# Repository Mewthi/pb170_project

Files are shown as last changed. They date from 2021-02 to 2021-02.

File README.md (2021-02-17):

LED - LA,LB,LC,LD,LE
Vstupy generovane citacom - (0-3)

    I       Q0    Q1    Q2    Q3    Q4
    00 -> ( 16 ->  8 ->  4 ->  2 ->  1)  
    01 -> ( 16 ->  1 ->  8 ->  2 ->  4) 
    10 -> ( 17 -> 10 ->  4 -> 20 -> 21)  
    11 -> (  4 -> 10 -> 17 -> 10 ->  4)  
  
Podrobna dokumentacia v /tex/main.pdf

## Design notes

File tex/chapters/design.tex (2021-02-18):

\newpage
\section*{Obvod}

Vstupy nášho obvodu sú generované čítačom:\\
a,Takto približne vyzeral čítač v simulátore Digital\\
\begin{center}
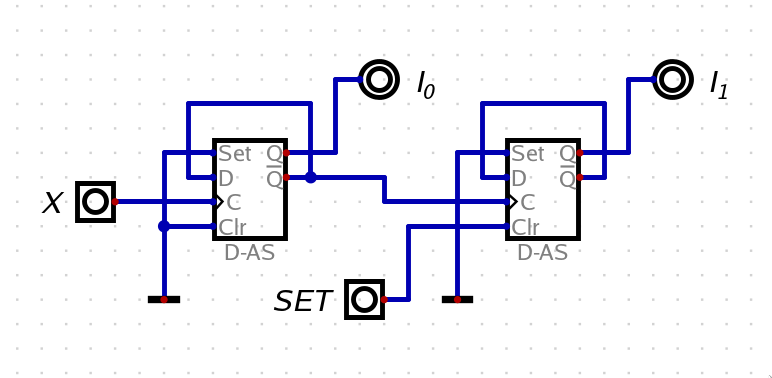
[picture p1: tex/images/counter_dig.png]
    
\end{center}
b,Pri návrhu PCB boli potrebné aj negácie a preto sme ich začali využívať.
\begin{center}
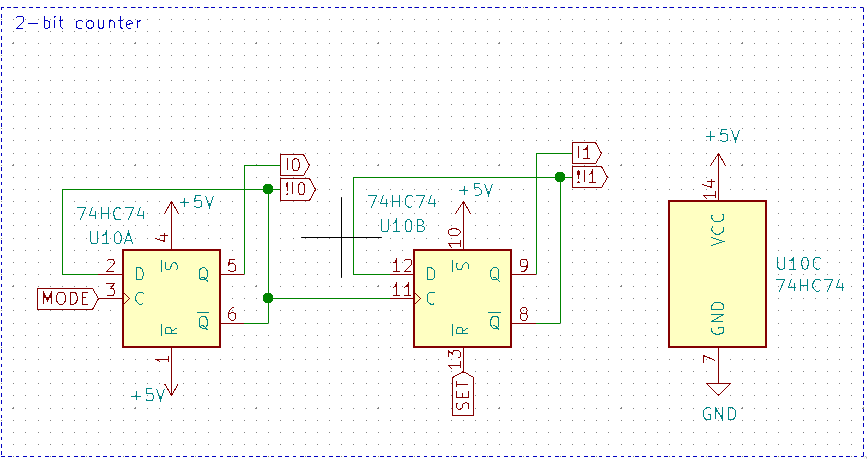
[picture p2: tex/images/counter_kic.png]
    	
\end{center}

\newpage
\noindent
Synchronizačný signál bol generovaný časovačom 555\\
\begin{center}
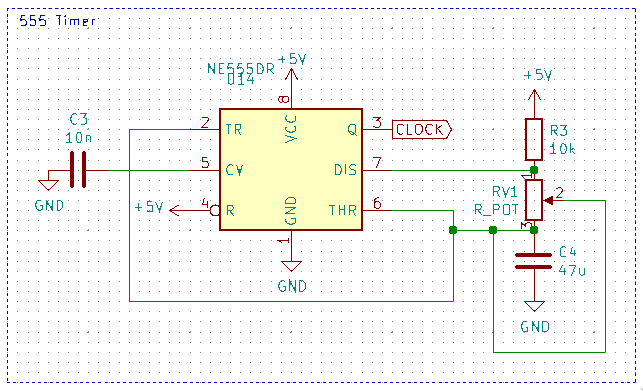
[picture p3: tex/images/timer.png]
    
\end{center}

\newpage
\noindent
Dve tlačítka ovládajúce tento obvod:\\
\noindent
a, tlačítko slúžiace na nastavenie prvého stavu sekvenčného obvodu:
\begin{center}
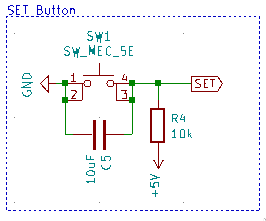
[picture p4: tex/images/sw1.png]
    
\end{center}
\noindent
b, tlačítko slúžiace na manipulovanie vstupov sekvenčného obvodu:
\begin{center}
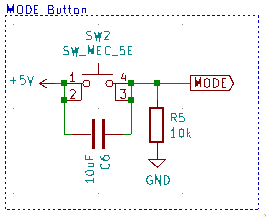
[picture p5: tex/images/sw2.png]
    
\end{center}

\newpage
\noindent
Samotný sekvenčný obvod v simulátore Digital a veľmi zjednodušená schéma celého obvodu:\\
\begin{center}
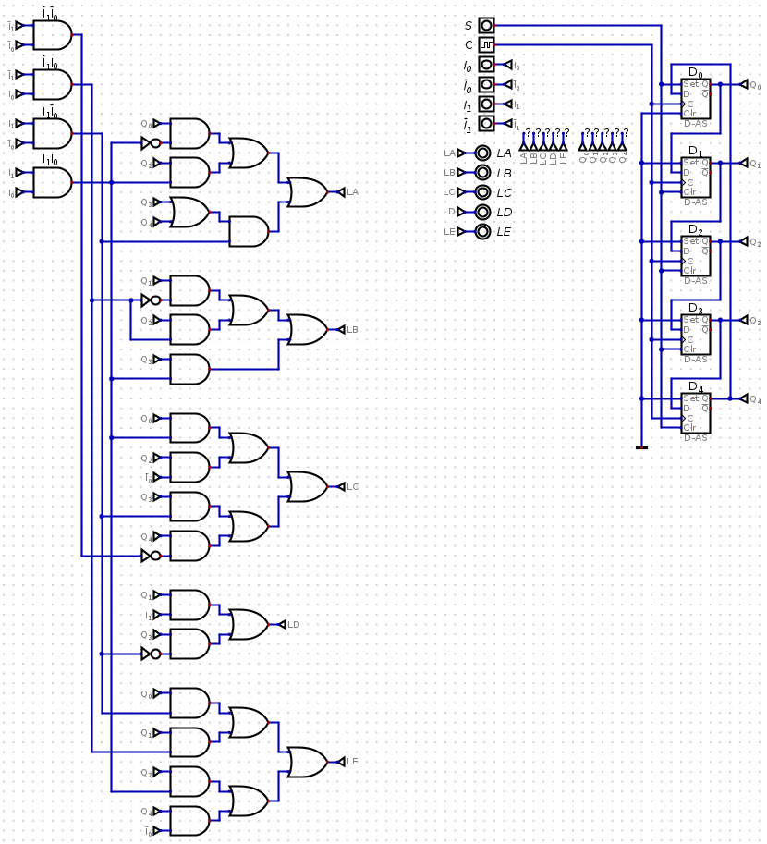
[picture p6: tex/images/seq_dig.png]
    
\end{center}

\begin{center}
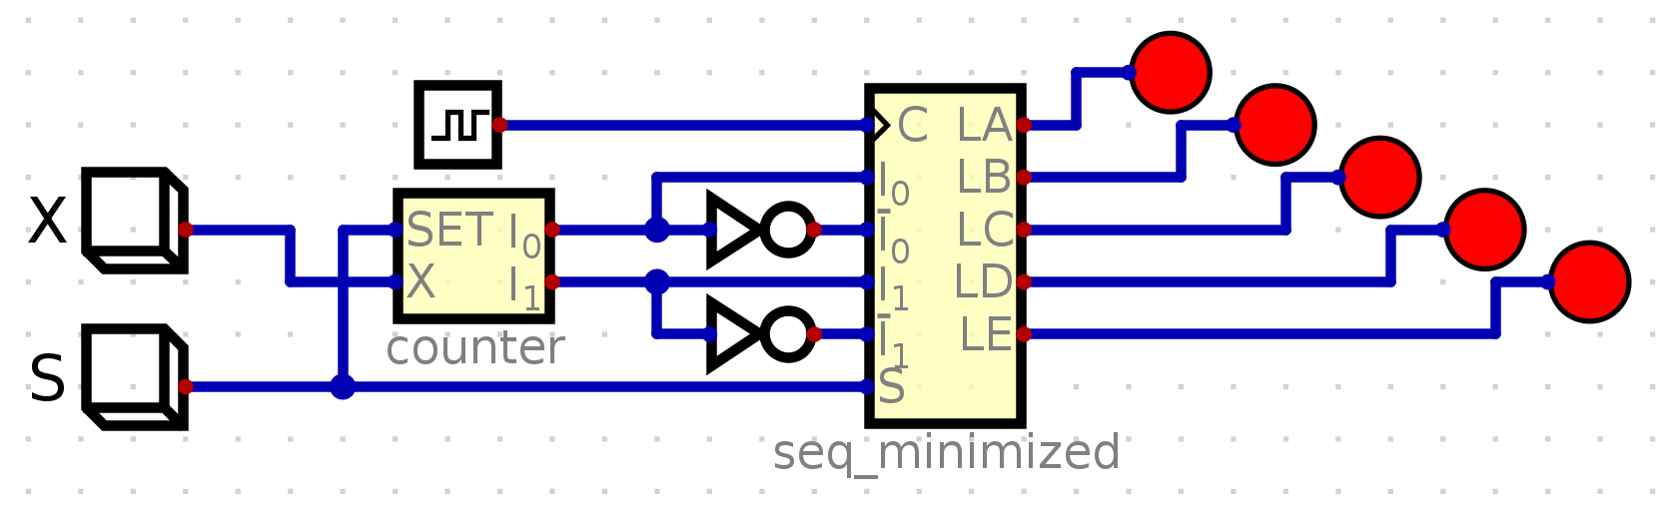
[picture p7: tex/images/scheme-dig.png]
    
\end{center}

\newpage
\noindent
Schéma celého obvodu
\begin{center}
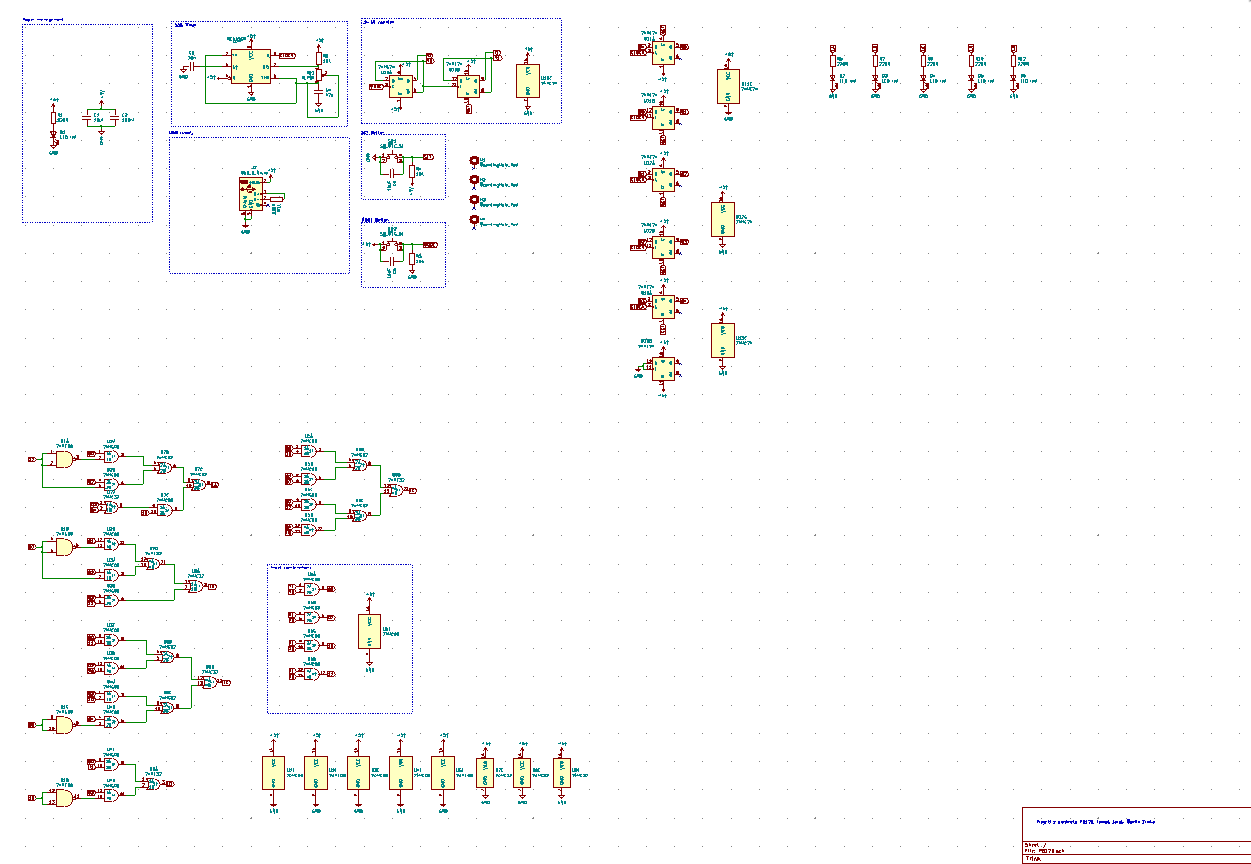
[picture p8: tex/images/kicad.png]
    
\end{center}
Schéma napájania, časovača, čítača a tlačítok.
\begin{center}
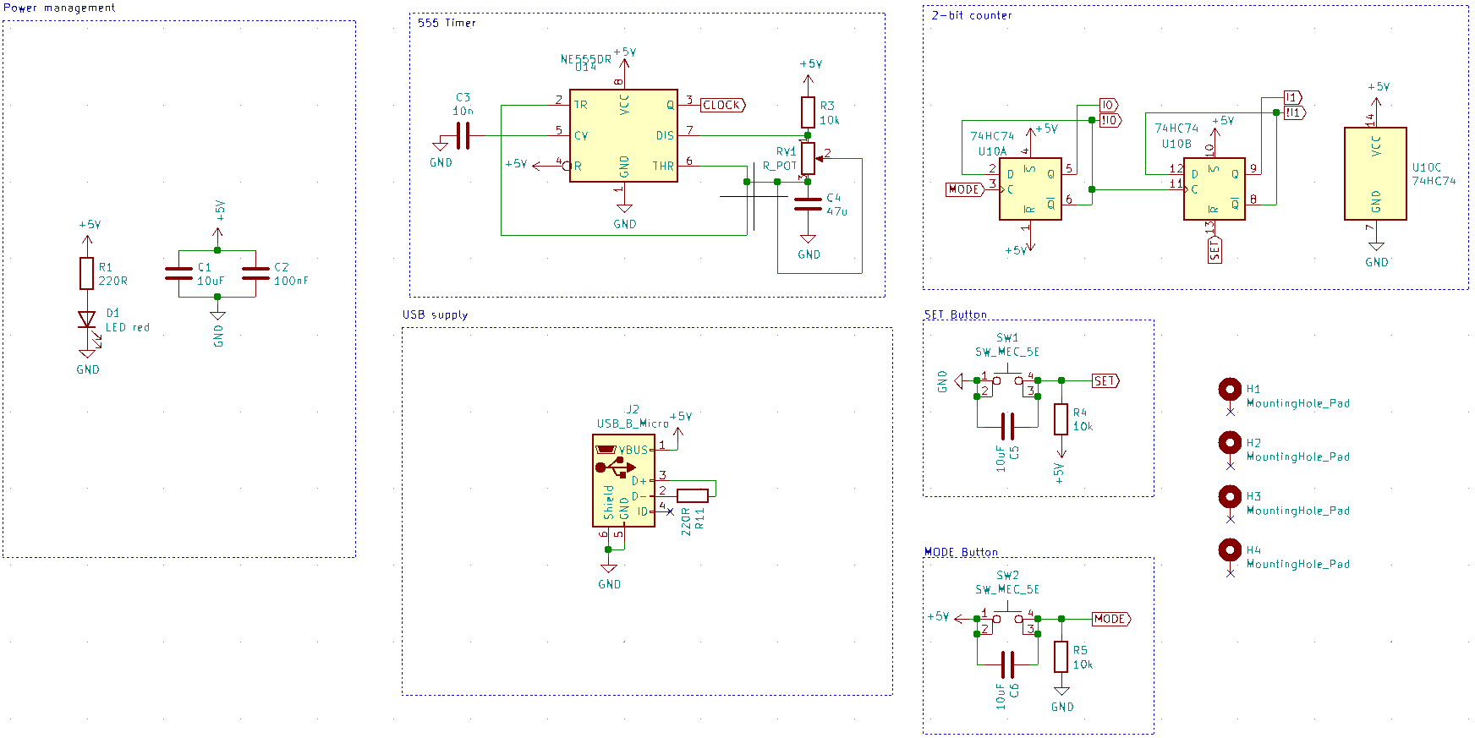
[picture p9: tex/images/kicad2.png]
    
\end{center}
\newpage
\noindent
Časť s klopnými obvodmi a LEDkami.
\begin{center}
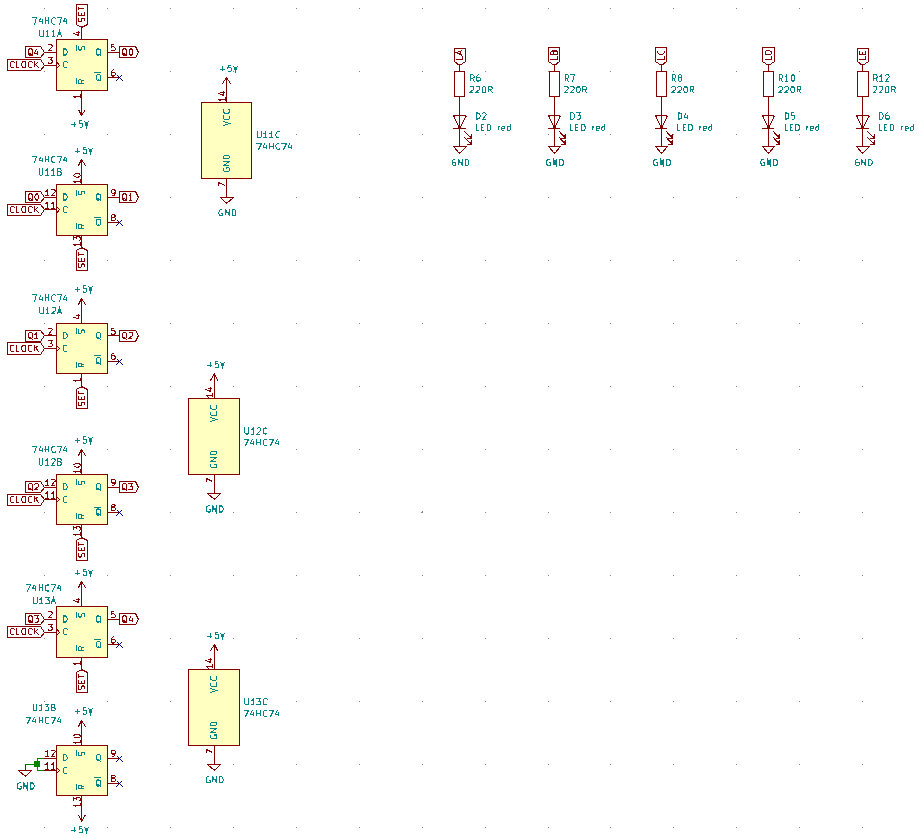
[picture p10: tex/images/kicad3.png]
    
\end{center} 
\newpage
\noindent
Logická časť obvodu.
\begin{center}
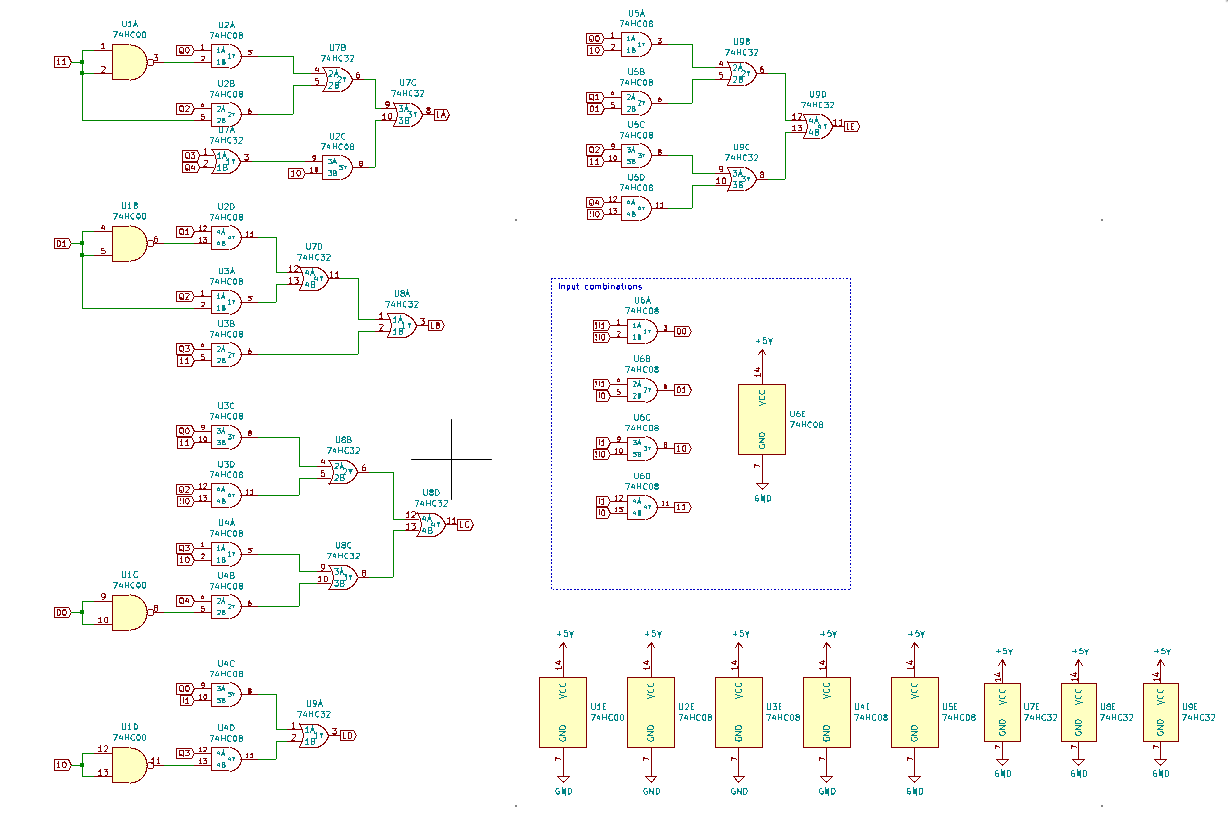
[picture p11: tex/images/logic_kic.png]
    
\end{center}
Prikladáme model výslednej PCB dosky.
\begin{center}
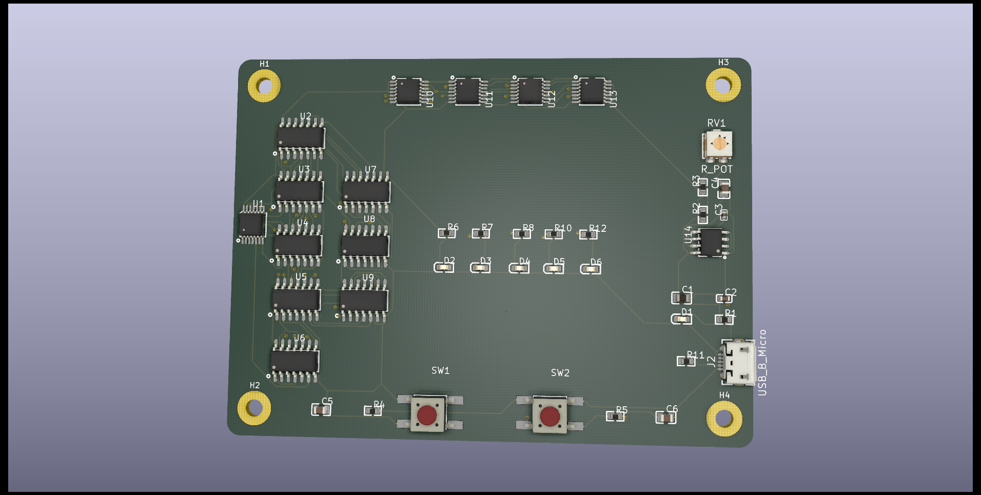
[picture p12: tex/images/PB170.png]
    
\end{center}

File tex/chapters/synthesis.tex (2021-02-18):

\graphicspath{{images/}}
\newcommand{\nt}[1]{\mkern 1.5mu\overline{\mkern-1.5mu#1\mkern-1.5mu}\mkern 1.5mu}

\section*{Syntéza sekvenčného obvodu}
\subsection*{Zadanie}
Našou úlohou bolo navrhnúť obvod, ktorý strieda farby blikaním niekoľkých farebných LED.
Tlačítkom change môže užívateľ vyberať medzi niekoľkými rôznymi sekvenciami blikania.
\subsection*{Priebeh návrhu}
Najprv sa bolo potrebné rozhodnúť z koľkých LEDiek bude náš obvod tvorený, ďalej
bolo potrebné rozhodnúť o počte druhov blikania týchto lediek.
Rozhodli sme sa, že náš obvod bude schopný riadiť blikanie 5 LEDiek štyrmi druhmi 
blikania.\\
Druhy blikania boli zvolené následovne: (Tieto desiatkové číslice predstavujú päťbitové binárne
čísla - jednotlivé LEDky)\\
\begin{center}
\begin{tabular}{c c c c c c c c c}
    16 &\rightarrow  &8 &\rightarrow  &4 &\rightarrow & 2 &\rightarrow  &1 \\
    16 &\rightarrow  &1 &\rightarrow  &8 &\rightarrow & 2 &\rightarrow  &4 \\
    17 &\rightarrow &10 &\rightarrow  &4 &\rightarrow &20 &\rightarrow &21 \\
    4 &\rightarrow  &10 &\rightarrow &17 &\rightarrow &10 &\rightarrow  &4 \\
\end{tabular}
\end{center}

\noindent
Ďalej sme vytvorili graf prechodov pre automat typu MEALY pre jednotlivé stavy tohto sekvenčného obvodu.
Vyzeral približne takto:
\begin{center}
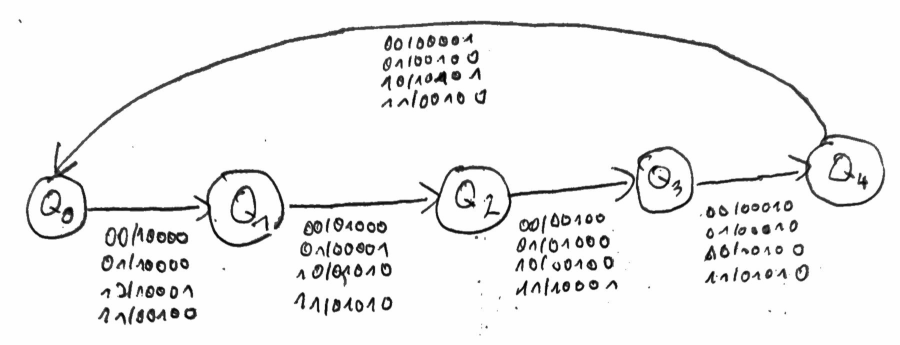
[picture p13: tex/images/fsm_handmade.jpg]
    
\end{center}

\newpage
\noindent
Na kódovanie vnútorných stavov $Q_{0}..Q_{4}$ sme použili kód 1zN a na ich uchovávanie
klopné obvody D. Vďaka použitému kódovaniu môžme budiace funkcie tohto sekvenčného 
obvodu odvodiť priamo z grafu prechodov.
\begin{align*}
    D_{0}^{n+1} &= Q_{4}\\
    D_{1}^{n+1} &= Q_{0}\\
    D_{2}^{n+1} &= Q_{1}\\
    D_{3}^{n+1} &= Q_{2}\\
    D_{4}^{n+1} &= Q_{3}\\
    LA &= Q_0(\nt{I_1}\nt{I_0} + \nt{I_1}I_0 + I_1\nt{I_0}) + Q_2(I_1I_0) +
    Q_3(I_1\nt{I_0}) + Q_4(I_1\nt{I_0})\\
       &=Q_0\nt{I_1I_0} + Q_2I_1I_0 + + (Q_3 + Q_4)I_1\nt{I_0}\\
    LB &= Q_1(\nt{I_1}\nt{I_0} + I_1\nt{I_0} + I_1I_0) + Q_2(\nt{I_1}I_0) + Q_3(I_1I_0)\\
       &= Q_1\nt{\nt{I_1}I_0} + Q_2\nt{I_1}I_0 + Q_3I_1I_0\\
    LC &= Q_0(I_1I_0) + Q_2(\nt{I_1}\nt{I_0} + I_1\nt{I_0}) + Q_3(I_1\nt{I_0}) +
    Q_4(\nt{I_1}I_0 + I_1\nt{I_0} + I_1I_0)\\
       &= Q_0I_1I_0 + Q_2\nt{I_0} + Q_3I_1\nt{I_0} + Q_4\nt{\nt{I_1}\nt{I_0}}\\
    LD &= Q_1(I_1\nt{I_0} + I_1I_0) + Q_3(\nt{I_1}\nt{I_0} + \nt{I_1}I_0 + I_1I_0)\\
       &= Q_1I_1 + Q_3\nt{I_1\nt{I_0}}\\
    LE &= Q_0(I_1\nt{I_0}) + Q_1(\nt{I_1}I_0) + Q_2(I_1I_0) + Q_4(\nt{I_1}\nt{I_0} +
    I_1\nt{I_0})\\
       &= Q_0I_1\nt{I_0} + Q_1\nt{I_1}I_0 + Q_2I_1I_0 + Q_4\nt{I_0}
\end{align*}

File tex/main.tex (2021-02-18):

\documentclass[12pt]{report}

\usepackage[utf8]{inputenc}
\usepackage{graphicx}
\graphicspath{{images/}}
\usepackage{amsmath}
\usepackage{geometry}
\geometry{
    left=1.5cm,
    right=1.5cm,
    top=1.5cm,
    bottom=1.5cm
}

\title{
{Záverečný projekt z predmetu PB170}\\
{\large Masarykova univerzita}\\
{\large Fakulta informatiky}
}
\author{Tomáš Jaroš a Martin Zimka}

\begin{document}

\maketitle

\input{chapters/synthesis.tex}
\input{chapters/design.tex}

\end{document}

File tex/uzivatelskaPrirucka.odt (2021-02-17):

UŽÍVATEĽSKÁ PRÍRUČKA

Sekvenčný obvod striedajúci farby blikaním 5 farebných LEDiek

Autori: Tomáš Jaroš a Martin Zimka


Všeobecný popis:

Blikanie LEDiek po napojení obvodu na napájanie spustíte stlačením SW1. Obvod začne blikať prvou sekvenciou. Postupním stláčaním tlačidla SW2 meníte sekvencie (druhá, tretia,…) až po štvrtej prídete zase na prvú (a takto stále dookola).

Ak chcete nejakú prebiehajúcu sekvenciu spustiť odzačiatku, stlačte tlačidlo SW1.

Rýchlosť blikania LEDiek si môžete upraviť potenciometrom.

Podporované sekvencie:

(LEDky sú označené zľava doprava písmenami A až E)

prvá ~> A → B → C → D → E

druhá ~> A → E → B → D → C

tretia ~> AE → BD → C → AC → ACE

štvrtá ~> AE → BD → C → BD

BAVTE SA :)

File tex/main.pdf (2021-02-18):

# Záverečný projekt z predmetu PB170

### Masarykova univerzita

### Fakulta informatiky

### Tomáš Jaroš a Martin Zimka

### February 18, 2021

## Syntéza sekvenčného obvodu

### Zadanie

Našou úlohou bolo navrhnúť obvod, ktorý strieda farby blikaním niekoľkých farebných LED. Tlačítkom change môže užívateľ vyberať medzi niekoľkými rôznymi sekvenciami blikania.

### Priebeh návrhu

Najprv sa bolo potrebné rozhodnúť z koľkých LEDiek bude náš obvod tvorený, dalej bolo potrebné ˇ rozhodnúť o počte druhov blikania týchto lediek. Rozhodli sme sa, že náš obvod bude schopný riadiť blikanie 5 LEDiek štyrmi druhmi blikania.
Druhy blikania boli zvolené následovne: (Tieto desiatkové číslice predstavujú päťbitové binárne čísla -jednotlivé LEDky)
16 → | 8 | → | 4 | → | 2 | → | 1
16 → | 1 | → | 8 | → | 2 | → | 4
17 → 10 → | 4 | → 20 → 21
4 | → 10 → 17 → 10 → | 4

Dalej sme vytvorili graf prechodov pre automat typu MEALY pre jednotlivé stavy tohto sekvenčného ˇ obvodu. Vyzeral približne takto:

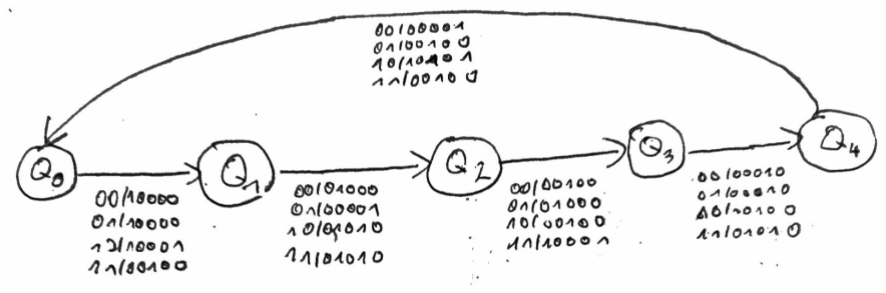
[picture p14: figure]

Na kódovanie vnútorných stavov Q0..Q4 sme použili kód 1zN a na ich uchovávanie klopné obvody D.
Vdaka použitému kódovaniu môžme budiace funkcie tohto sekvenčného obvodu odvodi ˇ | ť priamo z grafu
prechodov.

D

n+1
0 = Q4
D

n+1
1 = Q0
D

n+1
2 = Q1
D

n+1
3 = Q2
D

n+1
4 = Q3
LA = Q0(I1I0 + I1I0 + I1I0) + Q2(I1I0) + Q3(I1I0) + Q4(I1I0)
| = Q0I1I0 + Q2I1I0 + +(Q3 + Q4)I1I0

LB = Q1(I1I0 + I1I0 + I1I0) + Q2(I1I0) + Q3(I1I0)

| = Q1I1I0 + Q2I1I0 + Q3I1I0
LC = Q0(I1I0) + Q2(I1I0 + I1I0) + Q3(I1I0) + Q4(I1I0 + I1I0 + I1I0)
| = Q0I1I0 + Q2I0 + Q3I1I0 + Q4I1I0
LD = Q1(I1I0 + I1I0) + Q3(I1I0 + I1I0 + I1I0)
| = Q1I1 + Q3I1I0
LE = Q0(I1I0) + Q1(I1I0) + Q2(I1I0) + Q4(I1I0 + I1I0)
| = Q0I1I0 + Q1I1I0 + Q2I1I0 + Q4I0

## Obvod

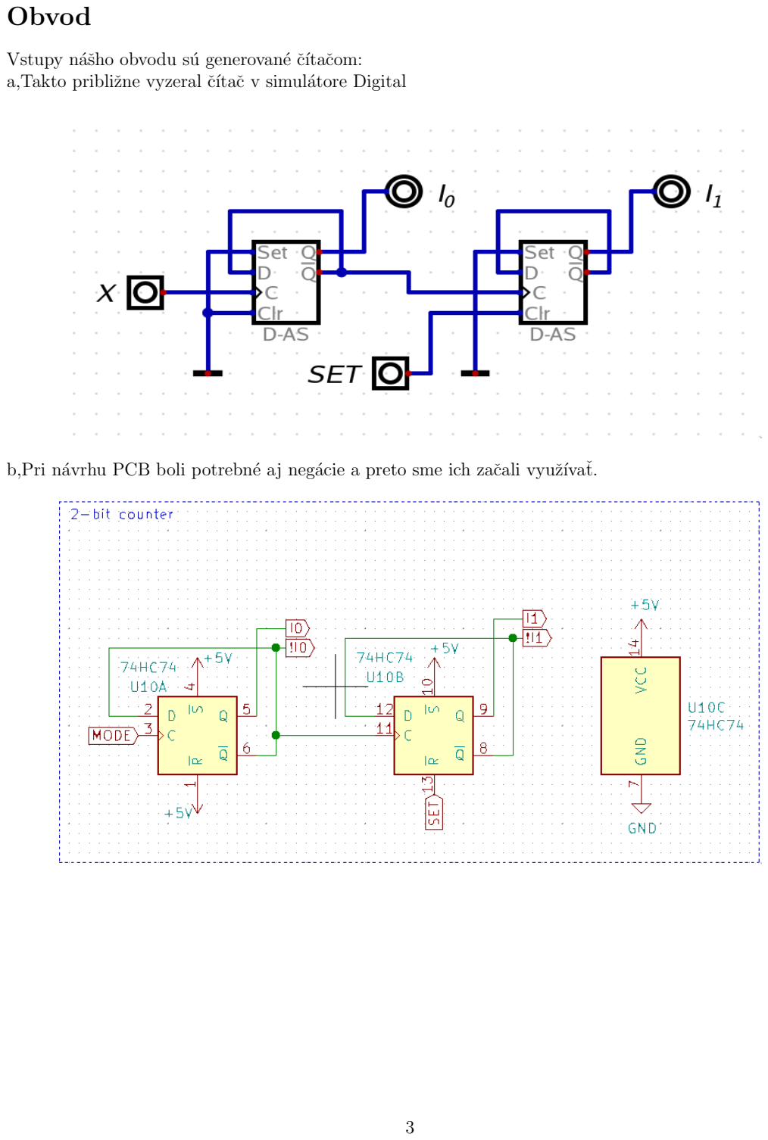
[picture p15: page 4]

Vstupy nášho obvodu sú generované čítačom: a,Takto približne vyzeral čítač v simulátore Digital

b,Pri návrhu PCB boli potrebné aj negácie a preto sme ich začali využívať.

Synchronizačný signál bol generovaný časovačom 555

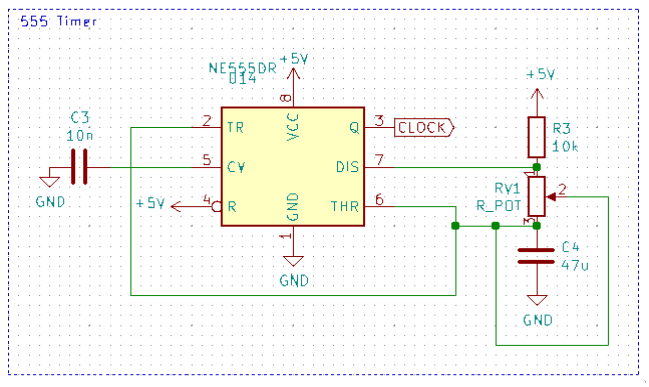
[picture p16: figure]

Dve tlačítka ovládajúce tento obvod:
a, tlačítko slúžiace na nastavenie prvého stavu sekvenčného obvodu:

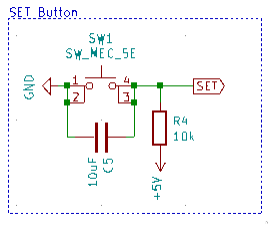
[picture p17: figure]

b, tlačítko slúžiace na manipulovanie vstupov sekvenčného obvodu:

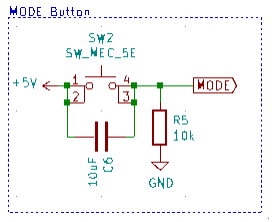
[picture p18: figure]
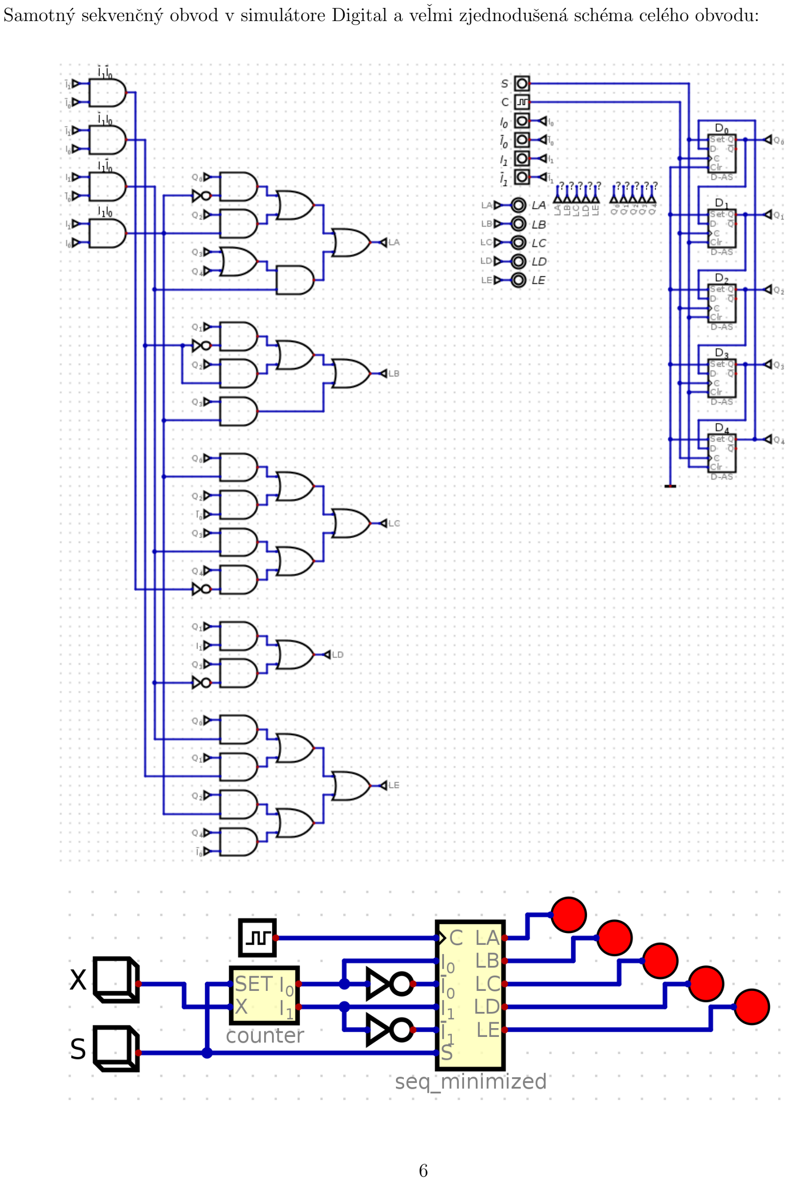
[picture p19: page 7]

Samotný sekvenčný obvod v simulátore Digital a veľmi zjednodušená schéma celého obvodu:

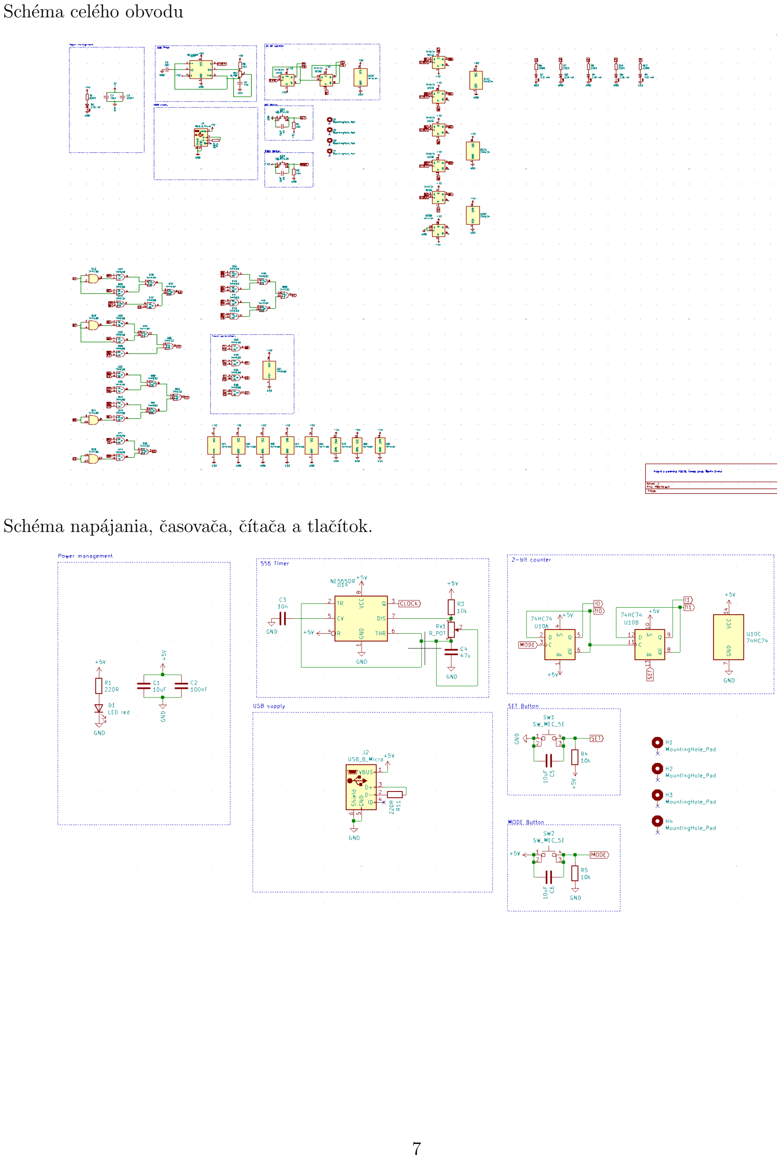
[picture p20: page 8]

Schéma celého obvodu

Schéma napájania, časovača, čítača a tlačítok.

Cas ˇ ť s klopnými obvodmi a LEDkami.

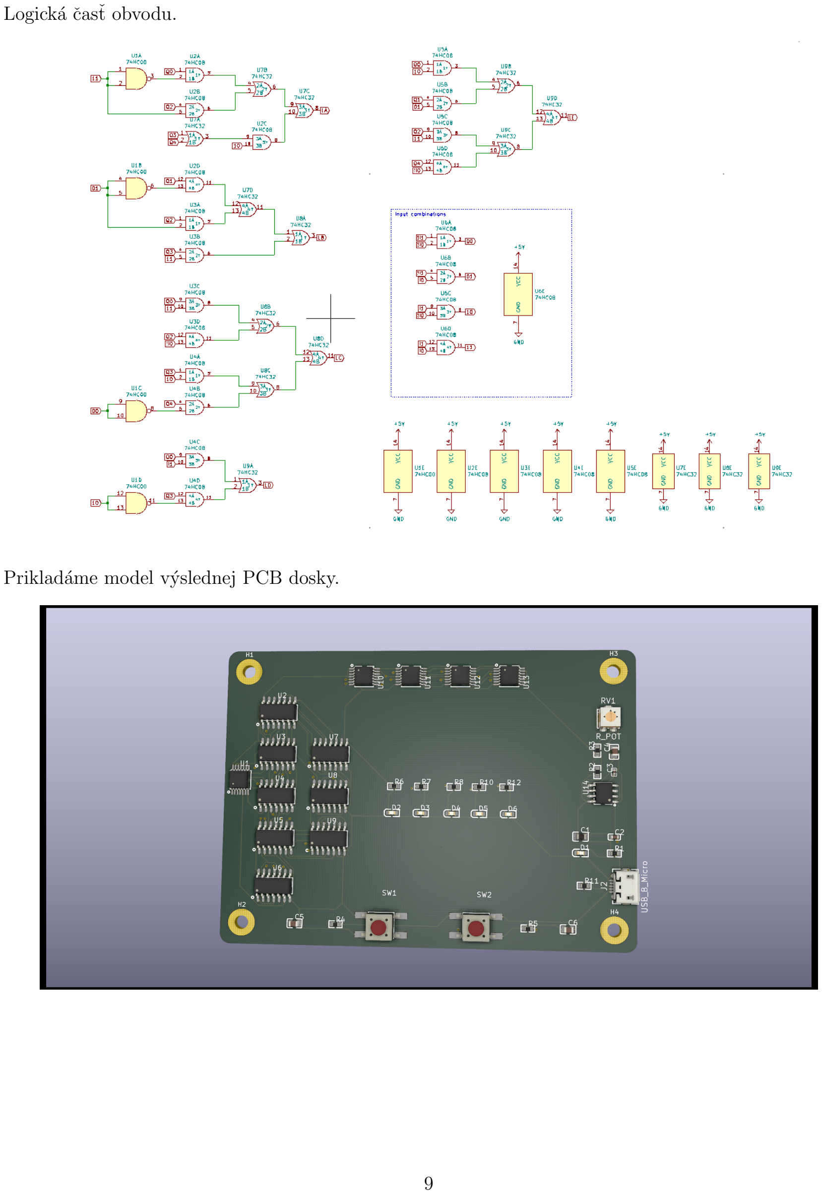
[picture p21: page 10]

Logická časť obvodu.

Prikladáme model výslednej PCB dosky.

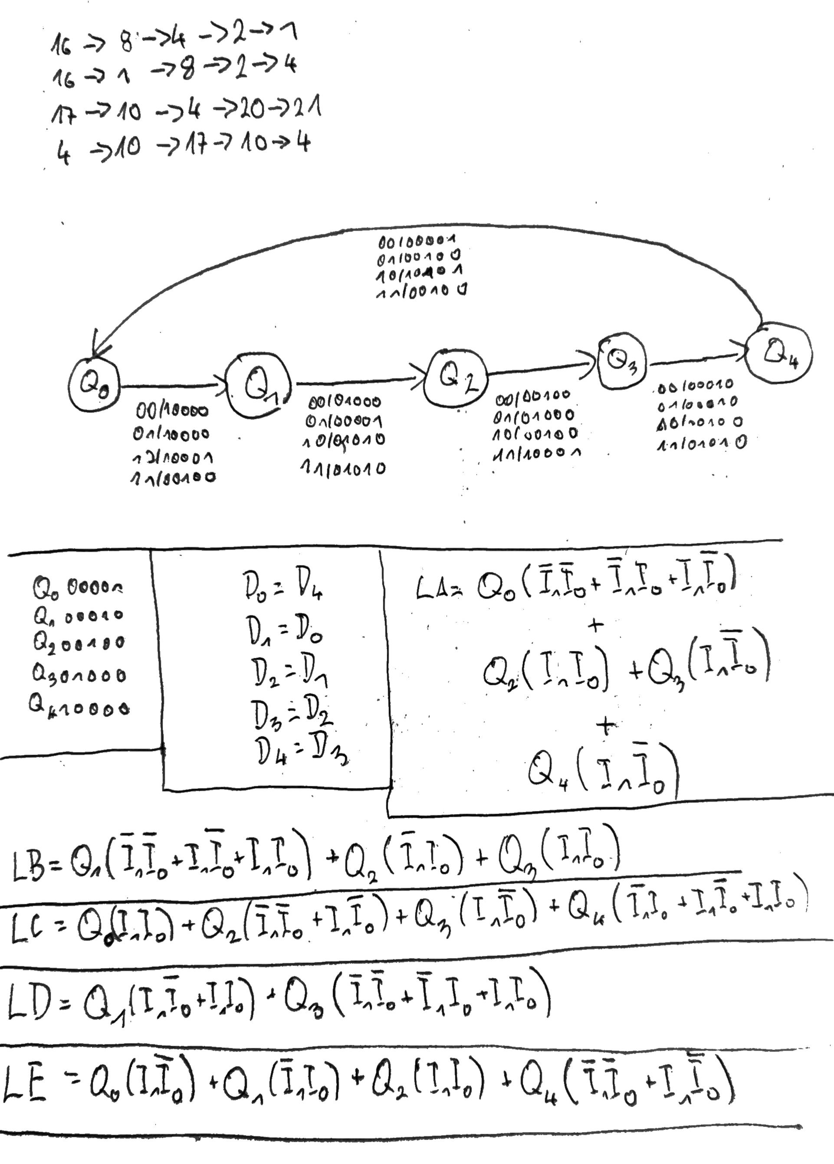
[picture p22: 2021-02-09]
tex/images/pb170-project.jpg

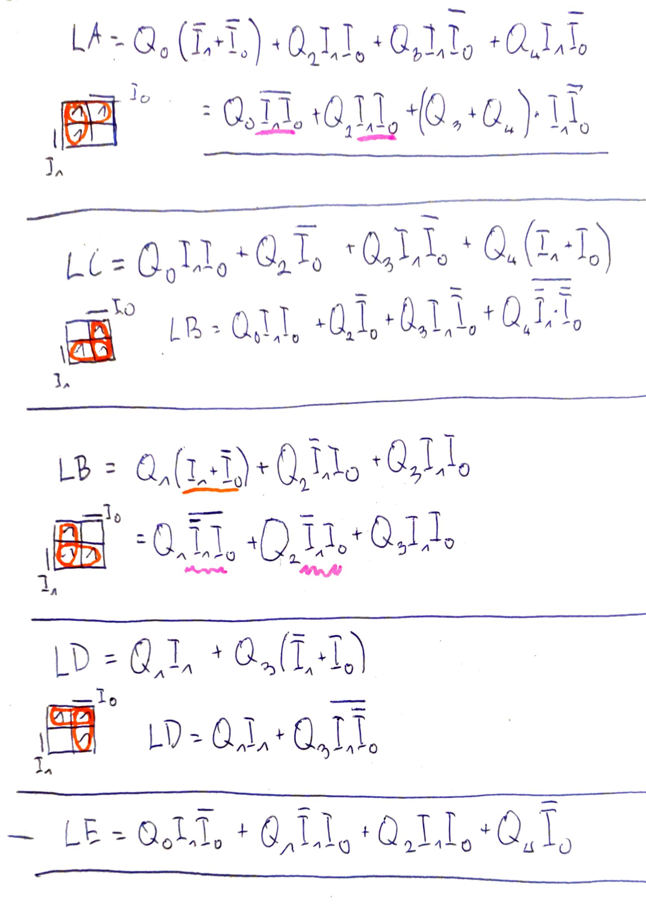
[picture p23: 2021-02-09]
tex/images/pb170-minimization.jpg

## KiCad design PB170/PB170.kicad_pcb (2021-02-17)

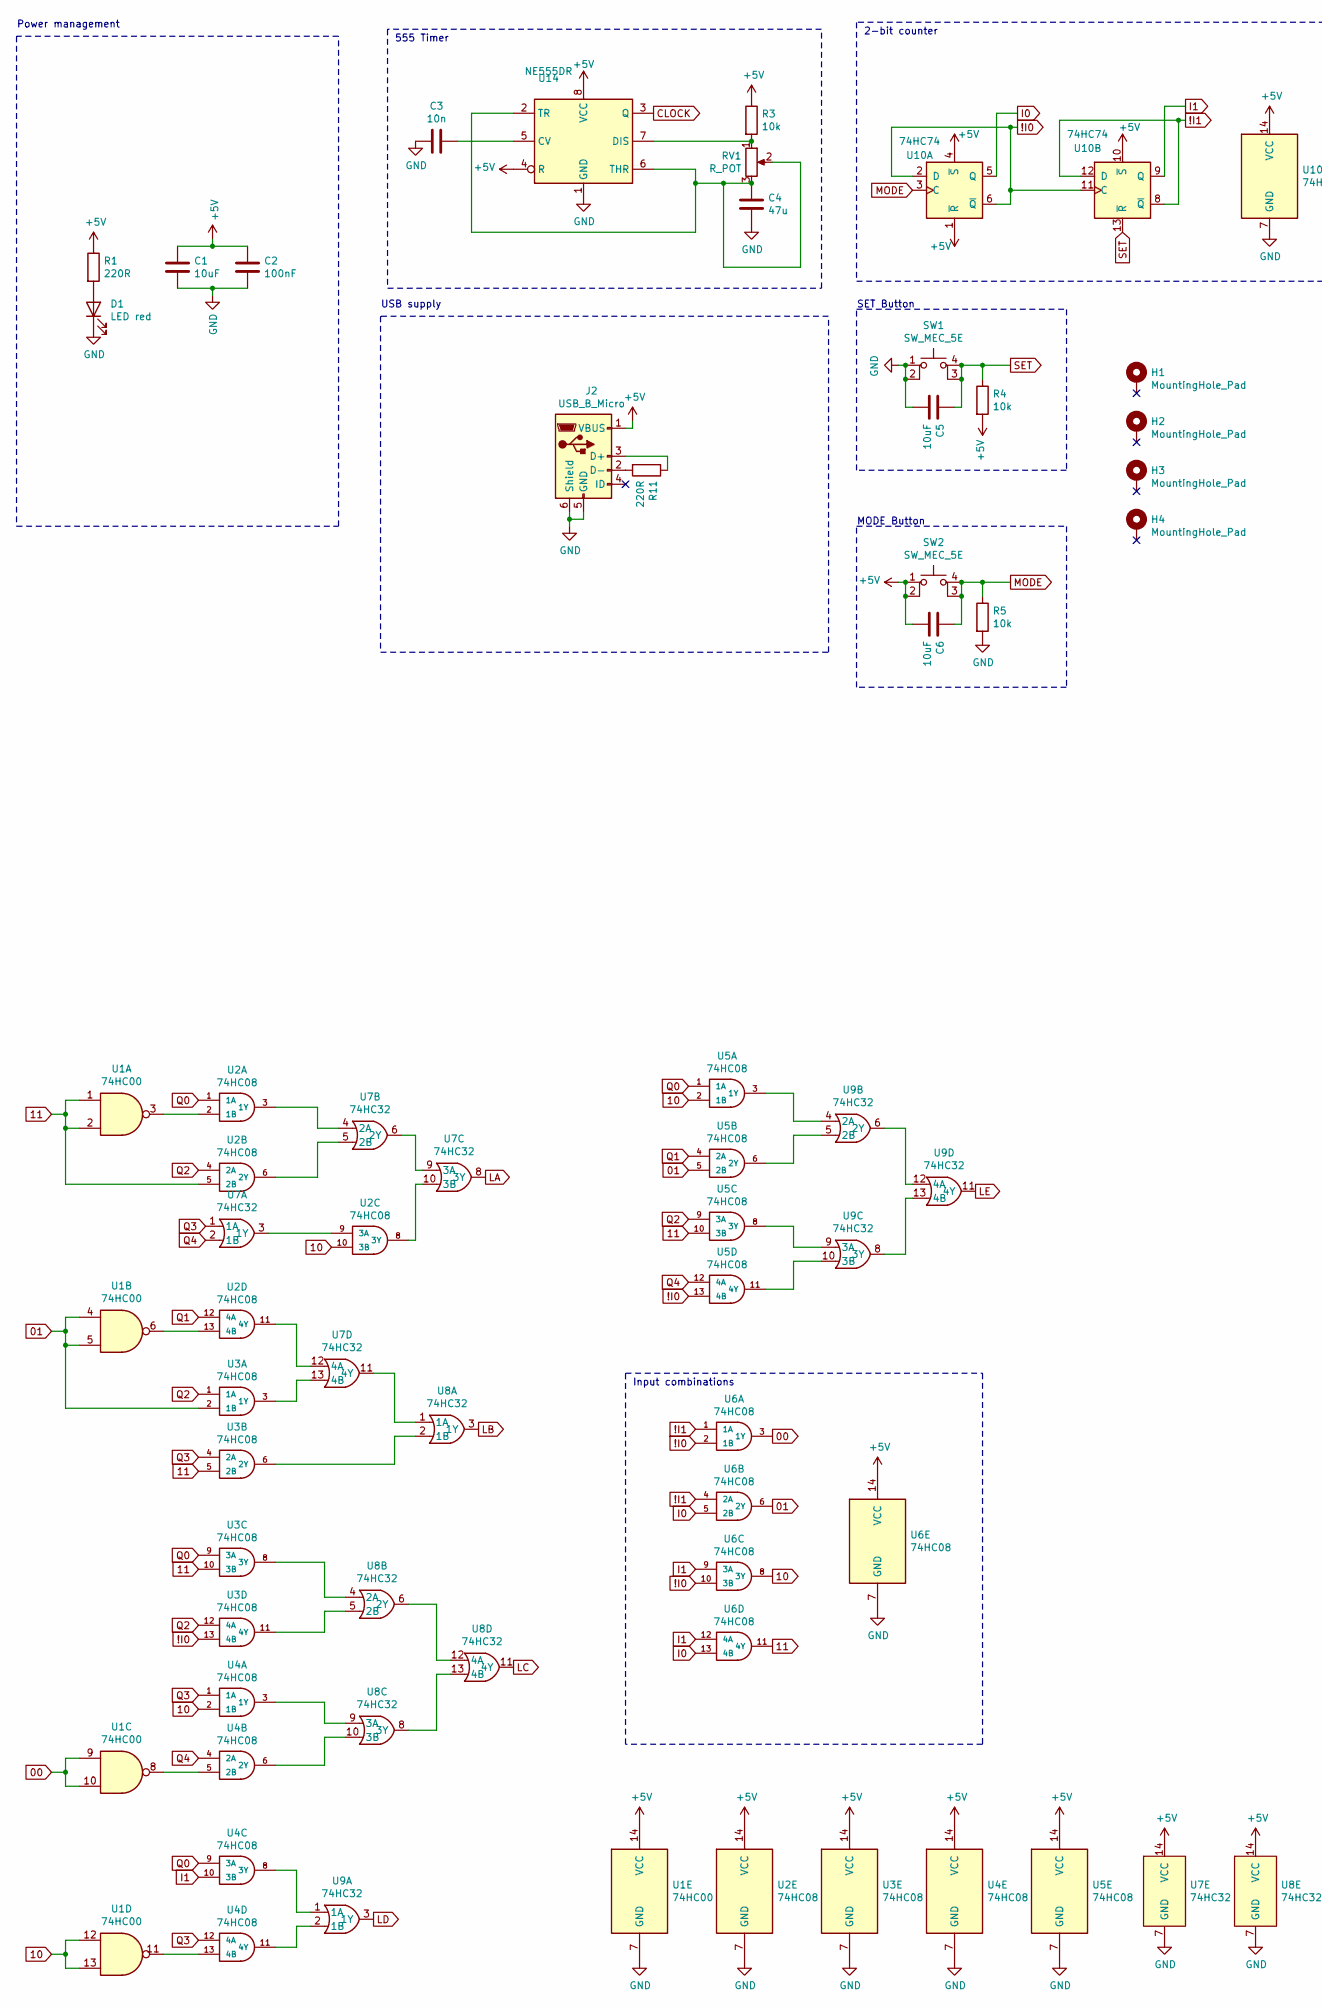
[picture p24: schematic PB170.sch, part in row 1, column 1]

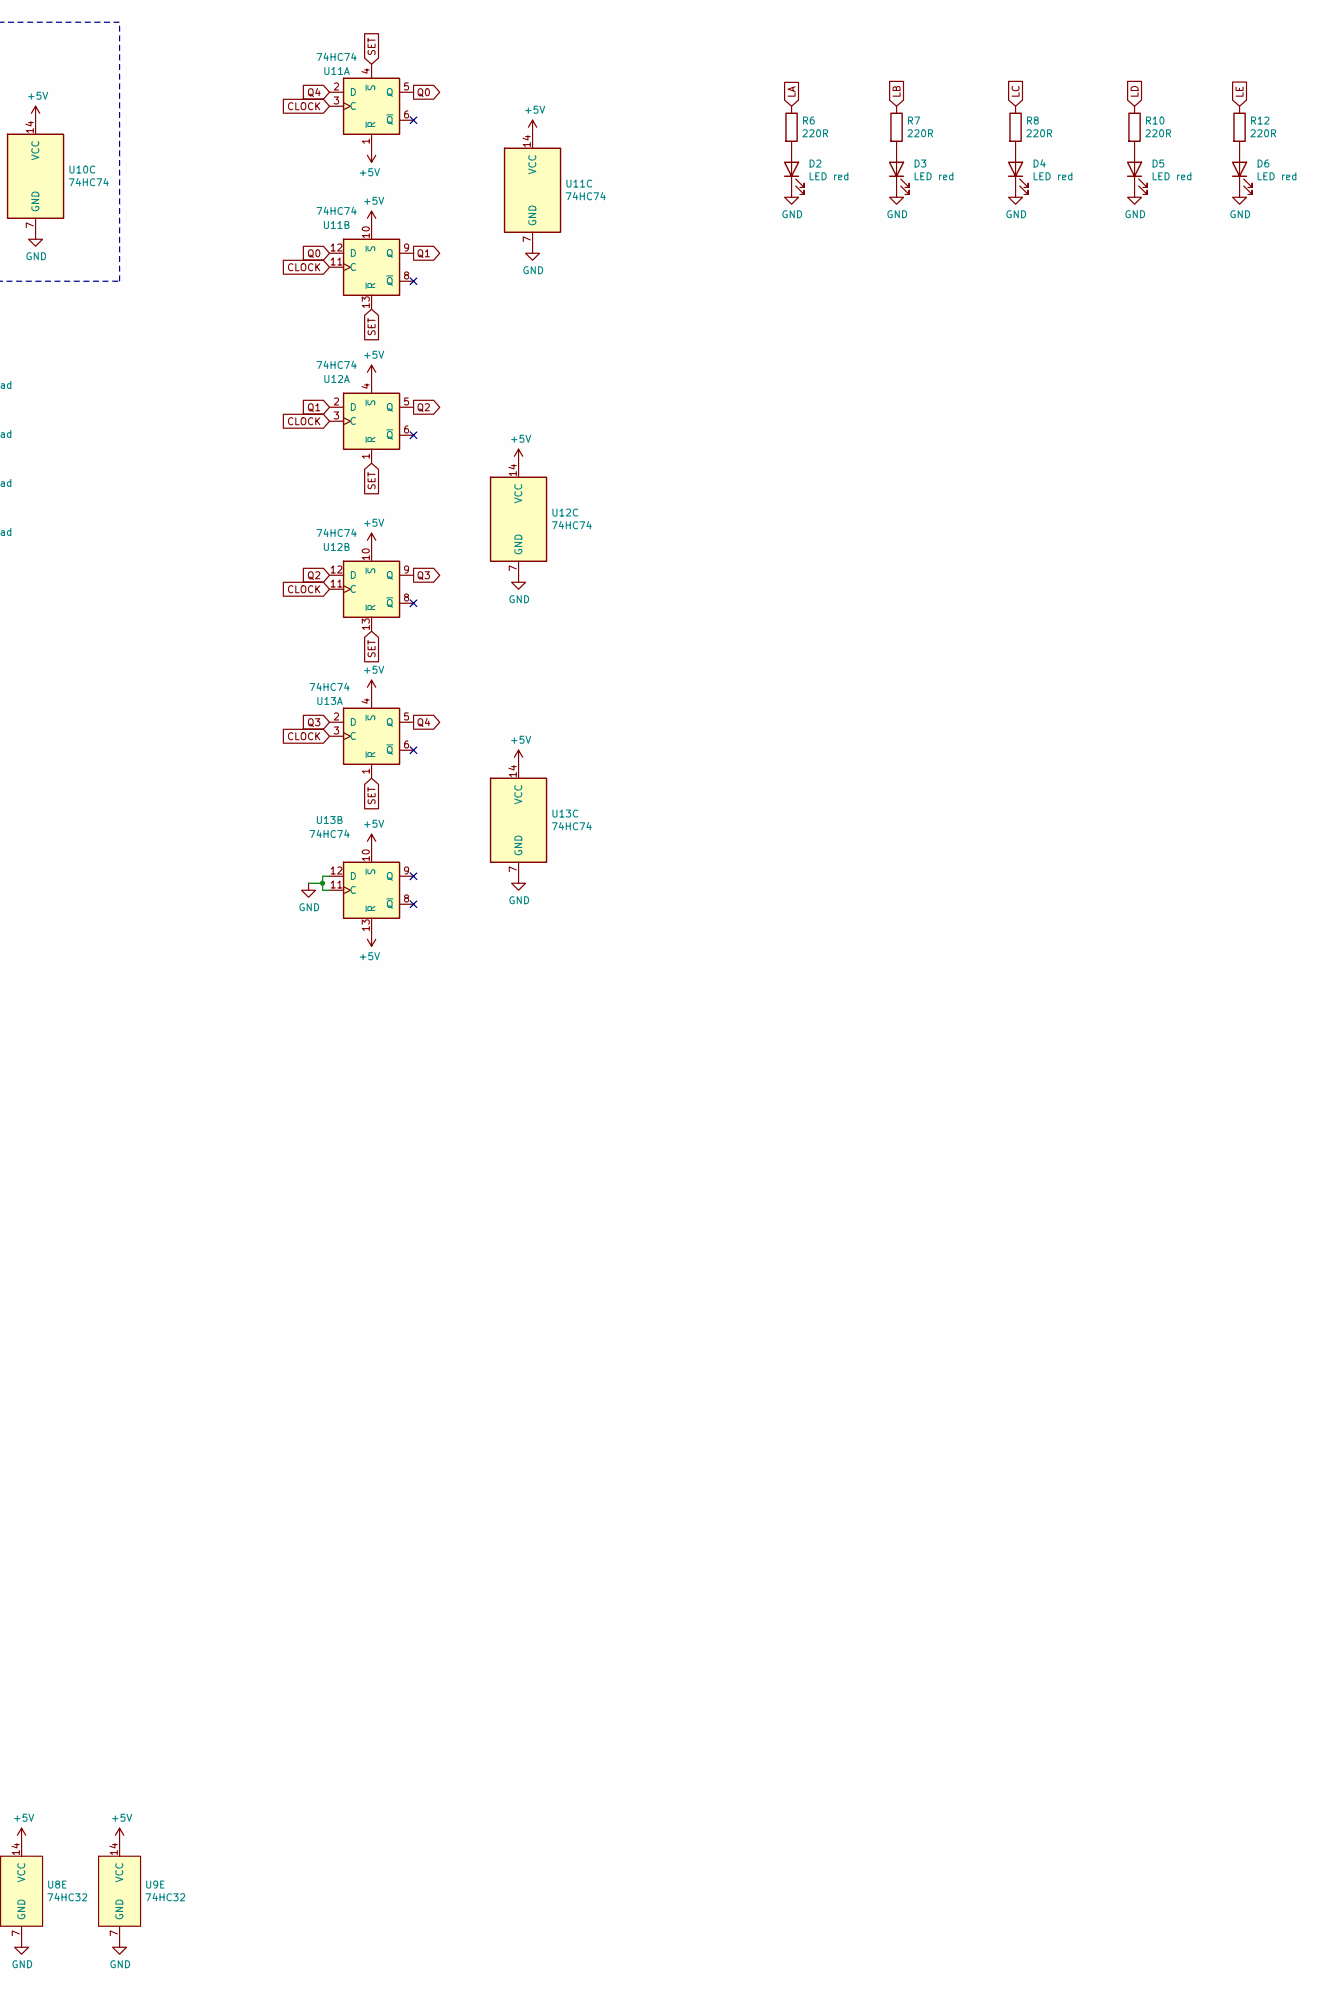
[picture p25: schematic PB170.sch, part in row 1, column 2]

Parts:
C1, C5, C6: 10uF; C0805; LCSC C15850
C2: 100nF; C0603; LCSC C14663
C3: 10n; C0402; LCSC C15195
C4: 47u; C0805; LCSC C45783
D1, D2, D3, D4, D5, D6: LED red; LED0603-R-RD; LCSC C2286
H1, H2, H3, H4: MountingHole_Pad; MountingHole_3.2mm_M3_Pad
J2: USB_B_Micro; MICRO-USB-SMD_MICROXNJ; LCSC C404969
R1, R6, R7, R8, R10, R11, R12: 220R; R0603; LCSC C22962
R3, R4, R5: 10k; R0603; LCSC C25804
RV1: R_POT; potentiometer10k; LCSC C132879
SW1, SW2: SW_MEC_5E; TactileSwitch_C381064; LCSC C381064
U1: 74HC00; TSSOP-14_L5.0-W4.4-P0.65-LS6.4-BL; LCSC C6807
U2, U3, U4, U5, U6: 74HC08; SOIC-14_L8.7-W3.9-P1.27-LS6.0-BL; LCSC C5593
U7, U8, U9: 74HC32; SOIC-14_L8.7-W3.9-P1.27-LS6.0-BL; LCSC C5632
U10, U11, U12, U13: 74HC74; TSSOP-14_L5.0-W4.4-P0.65-LS6.4-BL; LCSC C6761
U14: NE555DR; SOIC-8_L4.9-W3.9-P1.27-LS6.0-BL; LCSC C7593

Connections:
00: U1.9, U1.10, U6.3 (1Y)
01: U1.4, U1.5, U3.2 (1B), U5.5 (2B), U6.6 (2Y)
10: U1.12, U1.13, U2.10 (3B), U4.2 (1B), U5.2 (1B), U6.8 (3Y)
11: U1.1, U1.2, U2.5 (2B), U3.5 (2B), U3.10 (3B), U5.10 (3B), U6.11 (4Y)
!I0: U3.13 (4B), U5.13 (4B), U6.2 (1B), U6.10 (3B), U10.2 (D), U10.6 (~Q), U10.11 (C)
!I1: U6.1 (1A), U6.4 (2A), U10.8 (~Q), U10.12 (D)
+5V: C1.1, C2.1, C6.2, J2.1 (VBUS), R1.1, R3.1, R4.2, SW2.1, SW2.2, U1.14 (VCC), U2.14 (VCC), U3.14 (VCC), U4.14 (VCC), U5.14 (VCC), U6.14 (VCC), U7.14 (VCC), U8.14 (VCC), U9.14 (VCC), U10.1 (~R), U10.4 (~S), U10.10 (~S), U10.14 (VCC), U11.1 (~R), U11.10 (~S), U11.14 (VCC), U12.4 (~S), U12.10 (~S), U12.14 (VCC), U13.4 (~S), U13.10 (~S), U13.13 (~R), U13.14 (VCC), U14.4 (R), U14.8 (VCC); also elsewhere on the board
CLOCK: U11.3 (C), U11.11 (C), U12.3 (C), U12.11 (C), U13.3 (C), U14.3 (Q)
GND: C1.2, C2.2, C3.2, C4.2, C5.2, D1.1 (K), D2.1 (K), D3.1 (K), D4.1 (K), D5.1 (K), D6.1 (K), J2.5 (GND), J2.6 (Shield), R5.2, SW1.1, SW1.2, U1.7 (GND), U2.7 (GND), U3.7 (GND), U4.7 (GND), U5.7 (GND), U6.7 (GND), U7.7 (GND), U8.7 (GND), U9.7 (GND), U10.7 (GND), U11.7 (GND), U12.7 (GND), U13.7 (GND), U13.11 (C), U13.12 (D), U14.1 (GND)
I0: U6.5 (2B), U6.13 (4B), U10.5 (Q)
I1: U4.10 (3B), U6.9 (3A), U6.12 (4A), U10.9 (Q)
LA: R6.1, U7.8 (3Y)
LB: R7.1, U8.3 (1Y)
LC: R8.1, U8.11 (4Y)
LD: R10.1, U9.3 (1Y)
LE: R12.1, U9.11 (4Y)
MODE: C6.1, R5.1, SW2.3 (K), SW2.4 (A), U10.3 (C)
unnamed: C3.1, U14.5 (CV)
unnamed: C4.1, RV1.2, RV1.3, U14.2 (TR), U14.6 (THR)
unnamed: D1.2 (A), R1.2
unnamed: D2.2 (A), R6.2
unnamed: D3.2 (A), R7.2
unnamed: D4.2 (A), R8.2
unnamed: D5.2 (A), R10.2
unnamed: D6.2 (A), R12.2
unnamed: J2.2 (D-), R11.2
unnamed: J2.3 (D+), R11.1
unnamed: R3.2, RV1.1, U14.7 (DIS)
unnamed: U1.3, U2.2 (1B)
unnamed: U1.6, U2.13 (4B)
unnamed: U1.8, U4.5 (2B)
unnamed: U1.11, U4.13 (4B)
unnamed: U2.3 (1Y), U7.4 (2A)
unnamed: U2.6 (2Y), U7.5 (2B)
unnamed: U2.8 (3Y), U7.10 (3B)
unnamed: U2.9 (3A), U7.3 (1Y)
unnamed: U2.11 (4Y), U7.12 (4A)
unnamed: U3.3 (1Y), U7.13 (4B)
unnamed: U3.6 (2Y), U8.2 (1B)
unnamed: U3.8 (3Y), U8.4 (2A)
unnamed: U3.11 (4Y), U8.5 (2B)
unnamed: U4.3 (1Y), U8.9 (3A)
unnamed: U4.6 (2Y), U8.10 (3B)
unnamed: U4.8 (3Y), U9.1 (1A)
unnamed: U4.11 (4Y), U9.2 (1B)
unnamed: U5.3 (1Y), U9.4 (2A)
unnamed: U5.6 (2Y), U9.5 (2B)
unnamed: U5.8 (3Y), U9.9 (3A)
unnamed: U5.11 (4Y), U9.10 (3B)
unnamed: U7.6 (2Y), U7.9 (3A)
unnamed: U7.11 (4Y), U8.1 (1A)
unnamed: U8.6 (2Y), U8.12 (4A)
unnamed: U8.8 (3Y), U8.13 (4B)
unnamed: U9.6 (2Y), U9.12 (4A)
unnamed: U9.8 (3Y), U9.13 (4B)
Q0: U2.1 (1A), U3.9 (3A), U4.9 (3A), U5.1 (1A), U11.5 (Q), U11.12 (D)
Q1: U2.12 (4A), U5.4 (2A), U11.9 (Q), U12.2 (D)
Q2: U2.4 (2A), U3.1 (1A), U3.12 (4A), U5.9 (3A), U12.5 (Q), U12.12 (D)
Q3: U3.4 (2A), U4.1 (1A), U4.12 (4A), U7.1 (1A), U12.9 (Q), U13.2 (D)
Q4: U4.4 (2A), U5.12 (4A), U7.2 (1B), U11.2 (D), U13.5 (Q)
SET: C5.1, R4.1, SW1.3 (K), SW1.4 (A), U10.13 (~R), U11.4 (~S), U11.13 (~R), U12.1 (~R), U12.13 (~R), U13.1 (~R)

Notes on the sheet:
USB supply
Power management
555 Timer
SET Button
2-bit counter
Input combinations
MODE Button

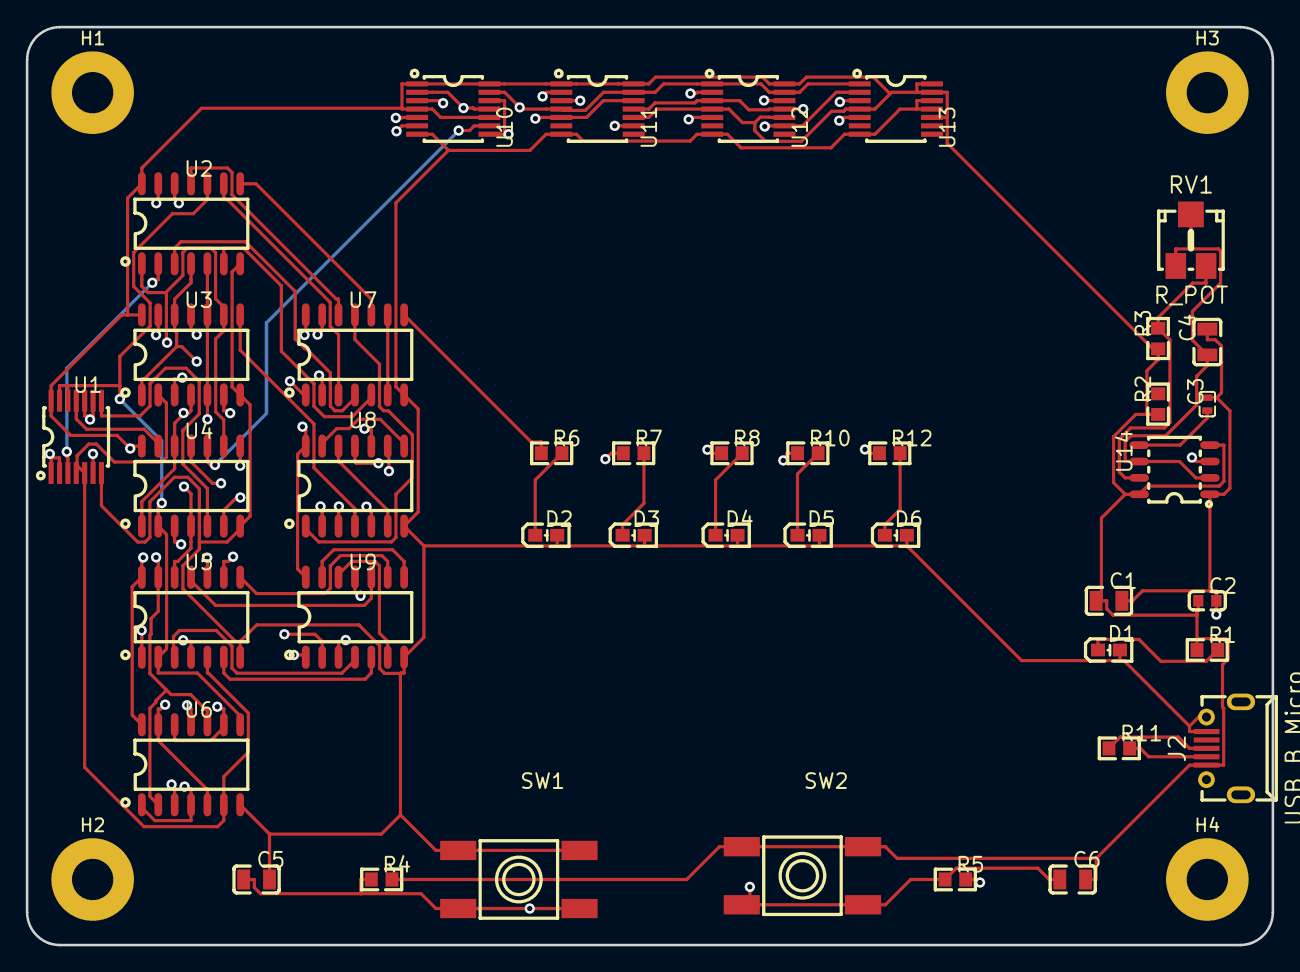
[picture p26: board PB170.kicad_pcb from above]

Board: 4 copper layers, 96.5 x 71.1 mm, 45 parts (0 on the bottom side), 61 nets.

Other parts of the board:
R2: 10k; R0603

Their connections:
+5V: R2.1; also elsewhere on the board

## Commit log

2021-02-09 first commit. hello world
    [PB170.kicad_pcb, PB170.sch, xor.sch]
2021-02-10 Flip-Flops changed
    [PB170.sch]
2021-02-11 11-02-2021 Martin
    [LA.sch, LBsch.sch, LC.sch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]
2021-02-11 added new parts
    [LB.sch, PB170.sch]
2021-02-11 KiCad crashing fixup, probably
    [PB170-template.sch, PB170.kicad_pcb, newParts.sch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]
2021-02-11 11-02-2021 02 Martin
    [LA.sch, LB.sch, LC.sch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]
2021-02-11 PB170.sch change
    [PB170.sch]
2021-02-11 11-02-2021 03 Martin
    [LD.sch, LE.sch]
2021-02-11 LA changed
    [LA.sch]
2021-02-11 added some labels
    [LA.sch, LB.sch, LBsch.sch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]
2021-02-12 12-02-2021 Martin
    [PB170.sch]
2021-02-12 labels changed
    [LA.sch, LB.sch, LC.sch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]
2021-02-12 added LEDs, mby we could try to start routing
    [LA.sch, LB.sch, LC.sch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]
2021-02-12 okay done
    [PB170.sch]
2021-02-12 refs changed
    [PB170.sch]
2021-02-12 annotated, needs footprints exported
    [PB170.sch]
2021-02-12 need needs capacitor footprints
    [LA.sch, LB.sch, LC.sch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]
2021-02-13 Capacitors footprints added, gl & hf routing
    [PB170.sch]
2021-02-13 13-02-2021 Martin
    [PB170.kicad_pcb]
2021-02-14 FreeRouting is a very useful java application
    [PB170.kicad_pcb]
2021-02-17 grounded unused pins, added 3D models and photo
    [PB170.kicad_pcb, PB170.sch]
